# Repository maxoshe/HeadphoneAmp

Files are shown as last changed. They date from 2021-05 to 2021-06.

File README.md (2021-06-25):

# HeadphoneAmp

In this project I have designed and implemented a Low Noise Headphone Amplifier. The purpose of this project was to gain a better understanding of the design process of printed circuit boards and to practice common engineering tasks such as drafting a schematic, generating a pcb layout from a schematic, generating a bill of materials and soldering components to a PCB.

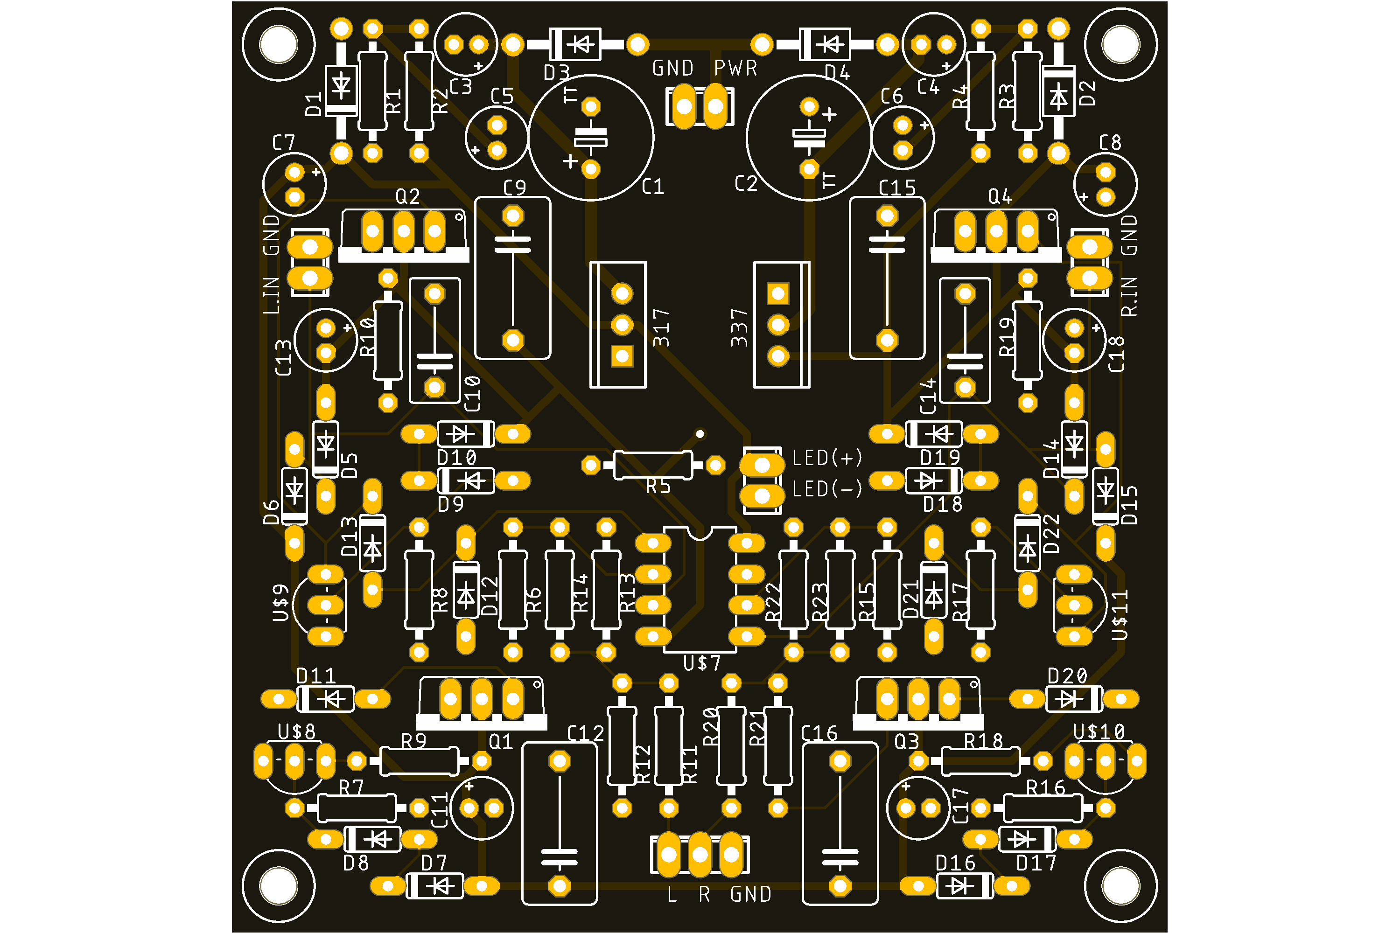
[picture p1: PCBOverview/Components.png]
pcb layout


## Design

The circuit is composed of three smaller circuits, a power supply and two mono
audio channels.
Dividing the entire schematic into three portions helped later with the board layout since I was able to easily separate the power supply from the signal path.

### Power Supply

The power supply receives 15V AC at the input terminal and outputs -15V DC and +15V DC at the output terminals. It achieves the rectification by using a combination of diodes, capacitors, resistors and voltage regulators.

### Audio Channels

Since this is a stereo amplifier, it is crucial to get the gain and signal to noise ratio of each individual mono channel to match. This is why the left and right audio channel schematics are exactly the same. There will still be some small differences since the tolerance of the components can’t be 0% but this difference is hardly noticeable.

The left and right audio channels both receive an audio signal and amplify it using a non inverting amplifier. The operational amplifier that is used in the circuit is a OP275, with two channels on the same IC chip.

## Layout

I’ve placed the power supply components in the upper corner of the board far from the signal path. By doing so I reduced the 60hz noise that can be caused by induction, since the wires carrying 15V AC are far from the wires that carry audio signal.
Another improvement to the layout was to set different trace thickness for power and signal traces.
The majority of the back panel was used as a ground plane. This helps to further reduce noise. For the connections from the PCB to external components I used terminal block plugs, it helped with keeping the design clean and flexible when it comes to connecting and disconnecting external components.

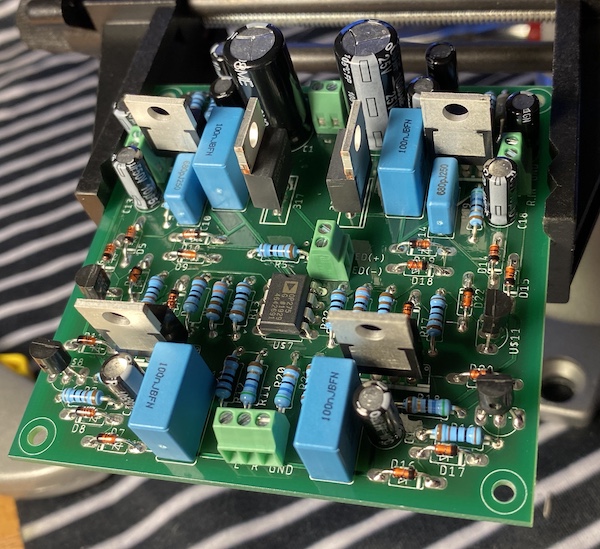
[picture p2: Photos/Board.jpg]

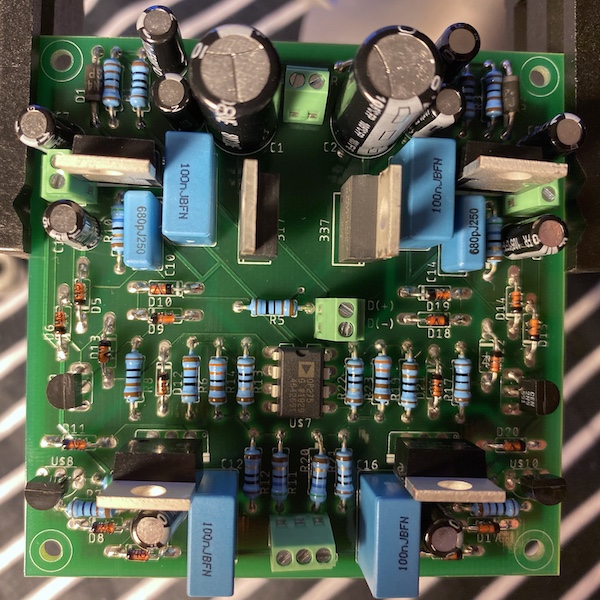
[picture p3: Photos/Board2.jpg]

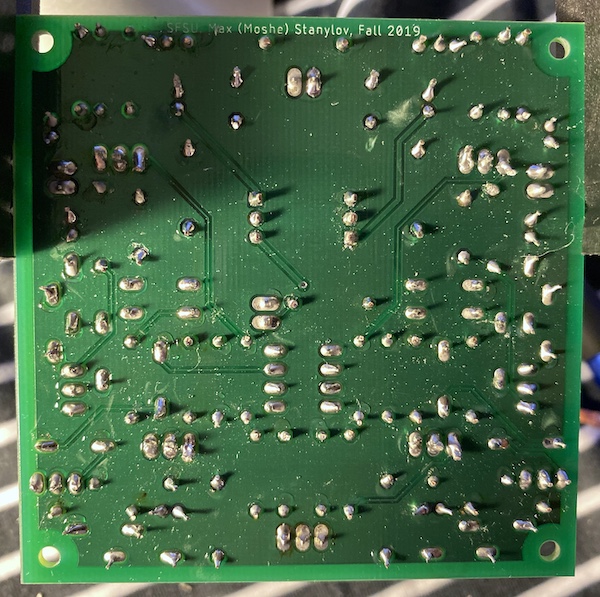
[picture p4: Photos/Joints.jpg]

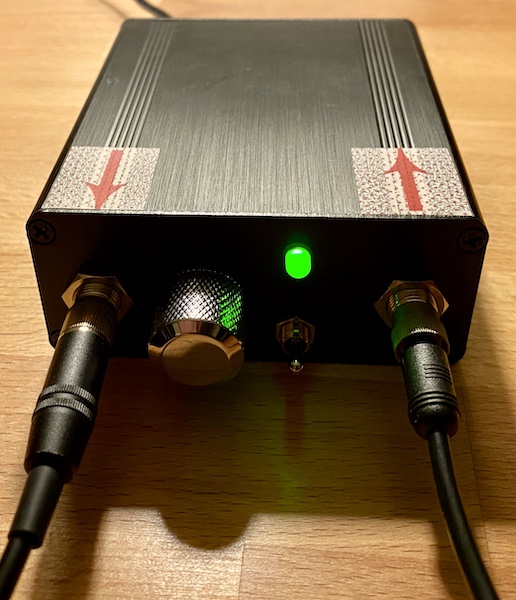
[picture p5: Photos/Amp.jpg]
enclosure


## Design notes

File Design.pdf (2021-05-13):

ENGR 301-01
Dec 17 2019
Moshe Stanylov

FINAL PROJECT: LOW NOISE HEADPHONE AMPLIFIER

Objective:
In this project I have designed and implemented a Low Noise Headphone Amplifier. The purpose of this project was to gain a better understanding of the design process of printed circuit boards and to practice common engineering tasks such as drafting a schematic, generating a pcb layout from a schematic, generating a bill of materials and soldering components to a PCB.

Design:

Schematic: The circuit is composed of three smaller circuits, a power supply and two mono audio channels.

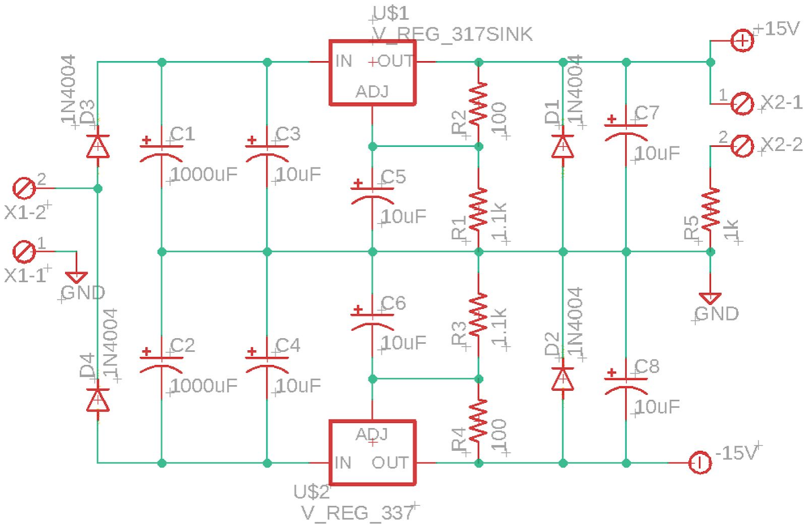
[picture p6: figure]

Fig.1 Power supply

The power supply in Fig.1 receives 15V AC at the input terminal labeled X1−2

from a
120V − 15V AC/AC transformer and outputs a − 15V DC and a + 15V DC at the output terminals labeled − 15V and + 15V . It achieves the rectification by using a combination of diodes, capacitors, resistors and voltage regulators.

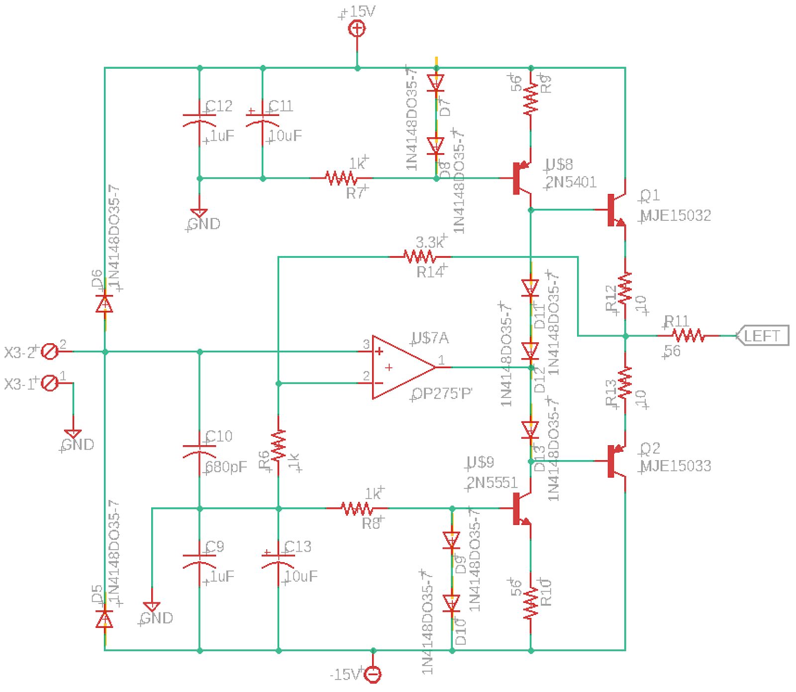
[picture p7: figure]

Fig.2 Left audio channel

Since this is a stereo amplifier, it is crucial to get the gain and signal to noise ratio of each individual mono channel to match. This is why the left and right audio channel schematics are exactly the same. There will still be some small differences since the tolerance of the components can’t be 0% but this difference is hardly noticeable.

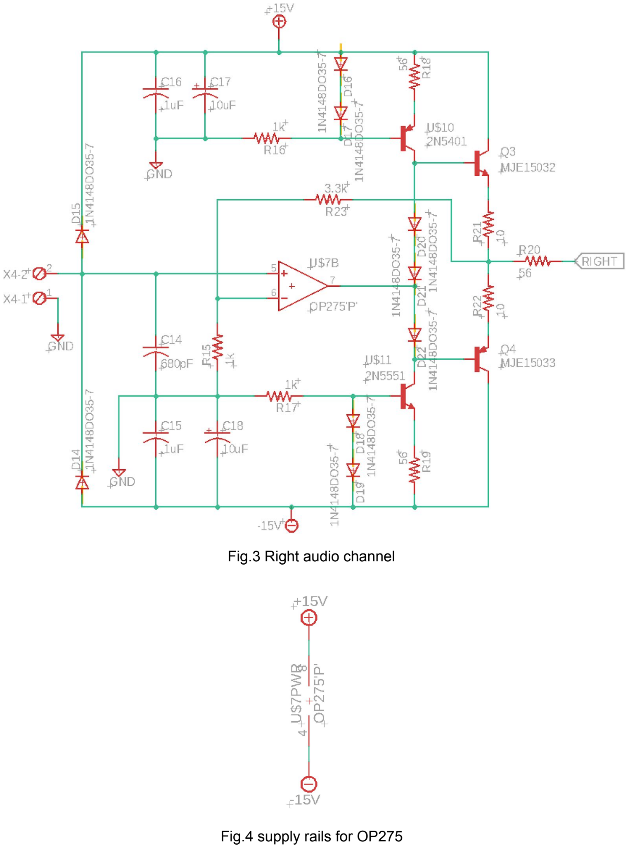
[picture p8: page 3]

Fig.3 Right audio channel

Fig.4 supply rails for OP275

The left and right audio channels both receive an audio signal and amplify it using a non inverting amplifier. The operational amplifier that is used in the circuit is a OP275, with two channels sharing the same IC.
Dividing the entire schematic into three portions helped later with the board layout since I was able to easily separate the power supply from the signal path.

Board: While working on the board layout I made sure that the packages that I use in the layout match with the components that I will be ordering. I also tried to keep things consistent and use components of different values from the same series.

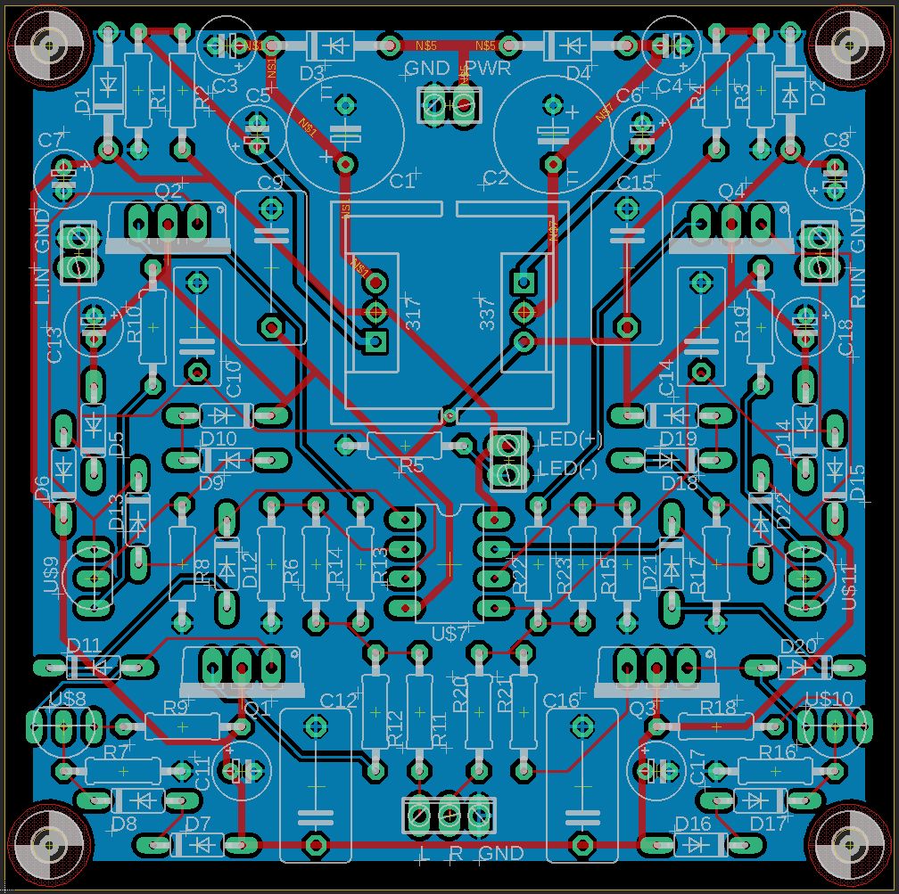
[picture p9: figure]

Fig.5 Board layout in Eagle

I’ve placed the power supply components in the upper corner of the board far from the signal path. By doing so I reduced the 60hz noise that can be caused by induction, since the wires carrying 15V AC are far from the wires that carry audio signal.
Another improvement to the layout was to define net class parameters, I’ve defined the wires carrying 15V AC to be the thickest, the wires carrying ± 15V DC thick and the rest was set to default.
The majority of the back panel was used as a ground plane. This helps to further reduce noise. For the connections from the PCB to external components I used terminal block plugs, it helped with keeping the design clean and flexible when it comes to connecting and disconnecting external components.
The final stage of the PCB layout was to create labels for the terminals and to make sure all of the component labels are placed in a way that is easy to read.

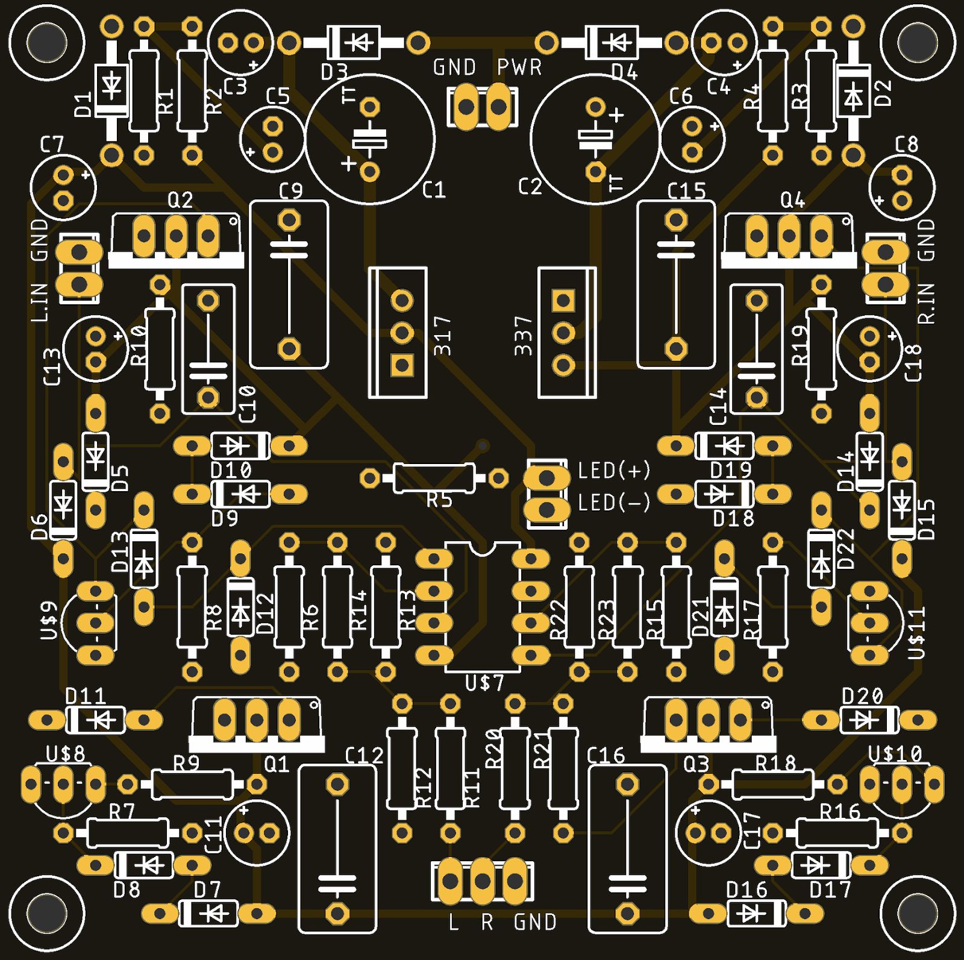
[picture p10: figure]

Fig.6 Board preview in Eagle

Components List:
Description | Part number | Quantity
Metal Film Resistors - 100Ω ± 1% | MBB02070C1000FCT00 | 2
Metal Film Resistors - 1.1kΩ ± 1% | MBB02070C1101FRP00 | 2
Metal Film Resistors - 1kΩ ± 1% | MBB02070C1001FC100 | 7
Metal Film Resistors - 56Ω ± 1% | MBB02070C5609FC100 | 6
Metal Film Resistors - 10Ω ± 1% | MBB02070C1009FCT00 | 4
Metal Film Resistors - 3.3kΩ ± 1% | MBB02070C3301FC100 | 2
Aluminum Electrolytic Capacitors - 1000μF ± 20% | EEU-FP1E102 | 2
Aluminum Electrolytic Capacitors - 10μF ± 20% | EEU-FR1H100 | 10
Film Capacitors - 0.68μF ± 5% | PHE450HK3680JR17 | 2
Film Capacitors - 0.1μF ± 5% | PHE450HA6100JR17 | 4
Diodes - Rectifiers | 1N4004GP-E3/73 | 4
Diodes - General Purpose | 1N4148TR | 18
Bipolar Transistors - PNP | 2N5401 | 2
Bipolar Transistors - NPN | 2N5551 | 2
Bipolar Transistors - NPN | MJE15032G | 2
Bipolar Transistors - PNP | MJE15033G | 2
Linear Voltage Regulators | LM317T/NOPB | 1
Linear Voltage Regulators | LM337T/NOPB | 1
Potentiometers - 10kΩ | PDB182-E420K-103A | 1
Op Amp - Dual Bipolar/JFET | OP275GPZ | 1
Fixed Terminal Blocks - 2 Positions | 1725656 | 4
Fixed Terminal Blocks - 3 Positions | 1725669 | 1
1/4" TRS | NYS230 | 2

Fuse - 1A | 0ADAP1000-RE | 1
Toggle Switch - SPDT ON-ON | 100SP1T1B1M1QEH | 1
Power Supply Jack - 5.5 × 2.1mm | B07MPS3QD8 | 1
Aluminum Enclosure - 88 × 38 × 100mm | LKHZ002 | 1
Table 1 Component List

Board Testing:

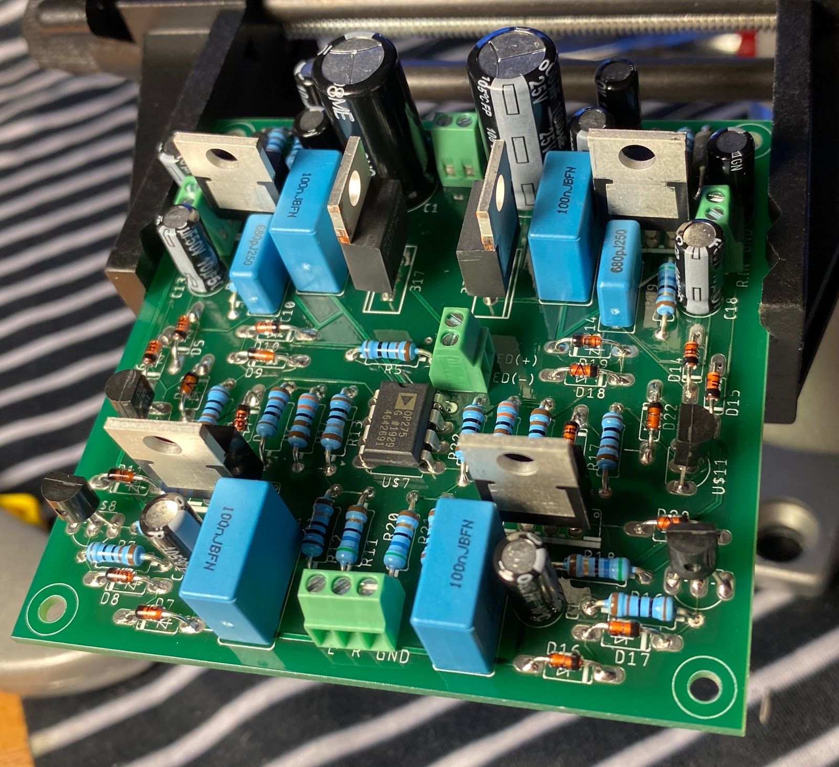
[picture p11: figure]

Fig.7 Board

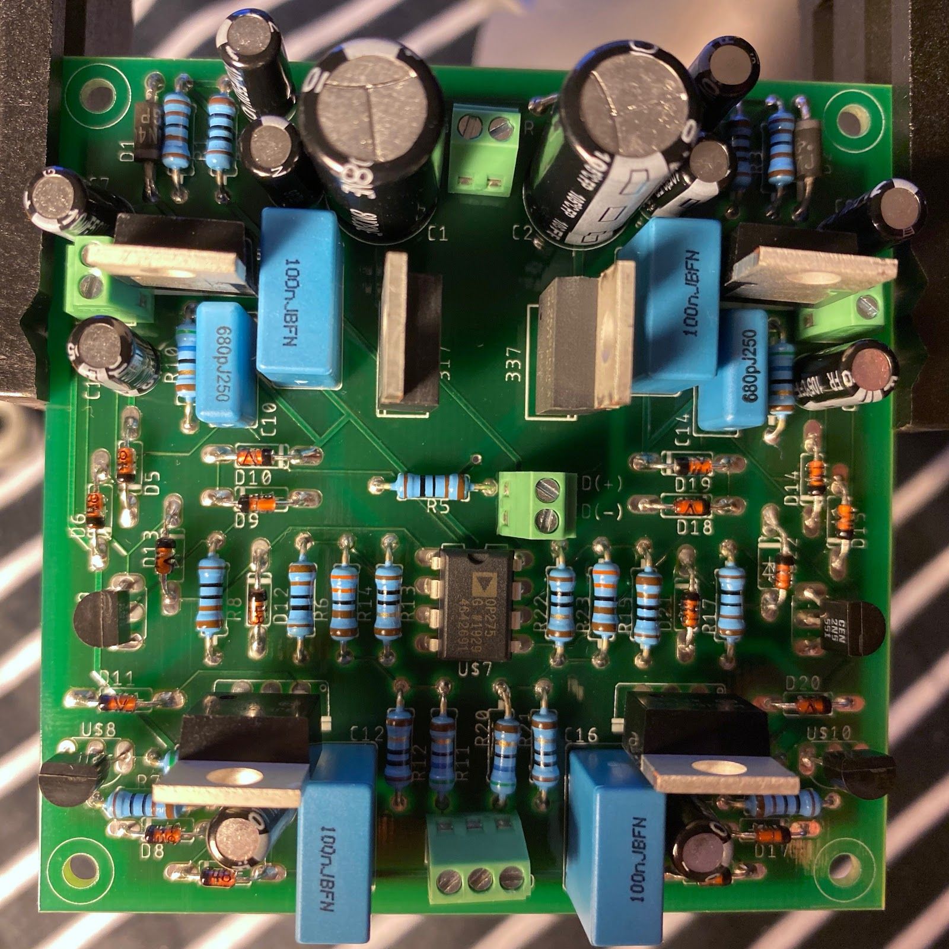
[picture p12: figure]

Fig.8 Board top

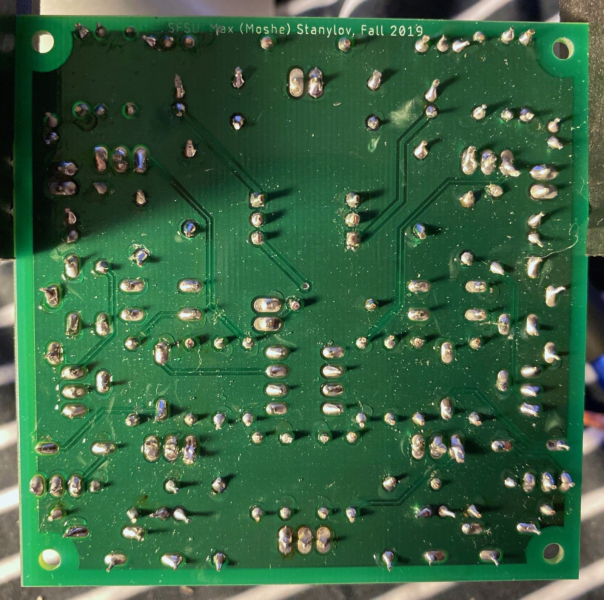
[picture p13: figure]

Fig.9 Board bottom

I’ve tested the board using a number of different inputs. The first test was done with an Audio Technica turntable, I’ve used an RCA to 3.5mm adapter in order to connect the output of the turntable to the input stage of the headphone amplifier and tested the potentiometer to see that I can control the volume and that the left and right channels are consistent. Everything worked but the potentiometer was wired backwards with the clockwise rotation decreasing the volume. Interchanging the connections on lugs 1 and 3 fixed the problem.
I then repeated the test twice using a laptop and a bass guitar as inputs, the circuit worked with both. The bass guitar was coming only from one channel since the output jack on a guitar is mono, this can be fixed by using an adapter.

Conclusion:
This project helped my understanding of the design and implementation process of printed circuit boards. It provided me with a lot of useful experience with Eagle. I learned how to create a board layout that takes into consideration the requirements of the design. Using terminal blocks for external components and paying attention to details such as package sizes of components, lead spacing and component placement made the assembling stage quick and easy.

Additional information:

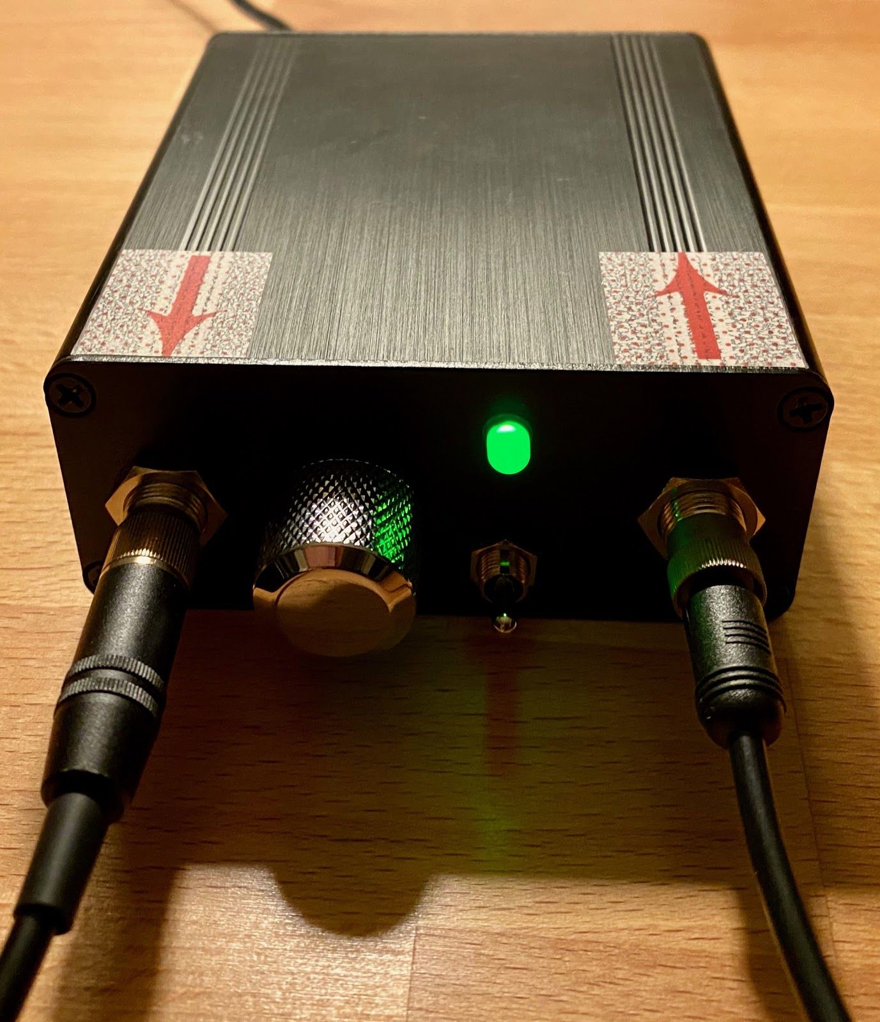
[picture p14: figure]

Fig.10 Enclosure

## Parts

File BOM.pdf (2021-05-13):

Component | Type | Part | Qty
Metal Film Resistor | 100Ω | MBB02070C1000FCT00 | 2
Metal Film Resistor | 1.1kΩ | MBB02070C1101FRP00 | 2
Metal Film Resistor | 1kΩ | MBB02070C1001FC100 | 7
Metal Film Resistor | 56Ω | MBB02070C5609FC100 | 6
Metal Film Resistor | 10Ω | MBB02070C1009FCT00 | 4
Metal Film Resistor | 3.3kΩ | MBB02070C3301FC100 | 2
Aluminum Electrolytic Capacitor | 1000μF | EEU-FP1E102 | 2
Aluminum Electrolytic Capacitor | 10μF | EEU-FR1H100 | 10
Film Capacitor | 0.68μF | PHE450HK3680JR17 | 2
Film Capacitor | 0.1μF | PHE450HA6100JR17 | 4
Diode | Rectifier | 1N4004GP-E3/73 | 4
Diode | General Purpos | 1N4148TR | 18
Bipolar Transistor | PNP | 2N5401 | 2
Bipolar Transistor | NPN | 2N5551 | 2
Bipolar Transistor | NPN | MJE15032G | 2
Bipolar Transistor | PNP | MJE15033G | 2
Linear Voltage Regulator | | LM317T/NOPB | 1
Linear Voltage Regulator | | LM337T/NOPB | 1
Potentiometer | 10kΩ | PDB182-E420K-103A | 1
Op Amp - Dual Bipolar | JFET | OP275GPZ | 1
Fixed Terminal Block | 2 Positions | 1725656 | 4
Fixed Terminal Block | 3 Positions | 1725669 | 1
1/4" TRS connector | | NYS230 | 2
Fuse | 1A | 0ADAP1000-RE | 1
Toggle Switch - SPDT ON-ON | | 100SP1T1B1M1QEH | 1
Power Supply Jack | | B07MPS3QD8 | 1
Aluminum Enclosure | 88 × 38 × 100mm | LKHZ002 | 1

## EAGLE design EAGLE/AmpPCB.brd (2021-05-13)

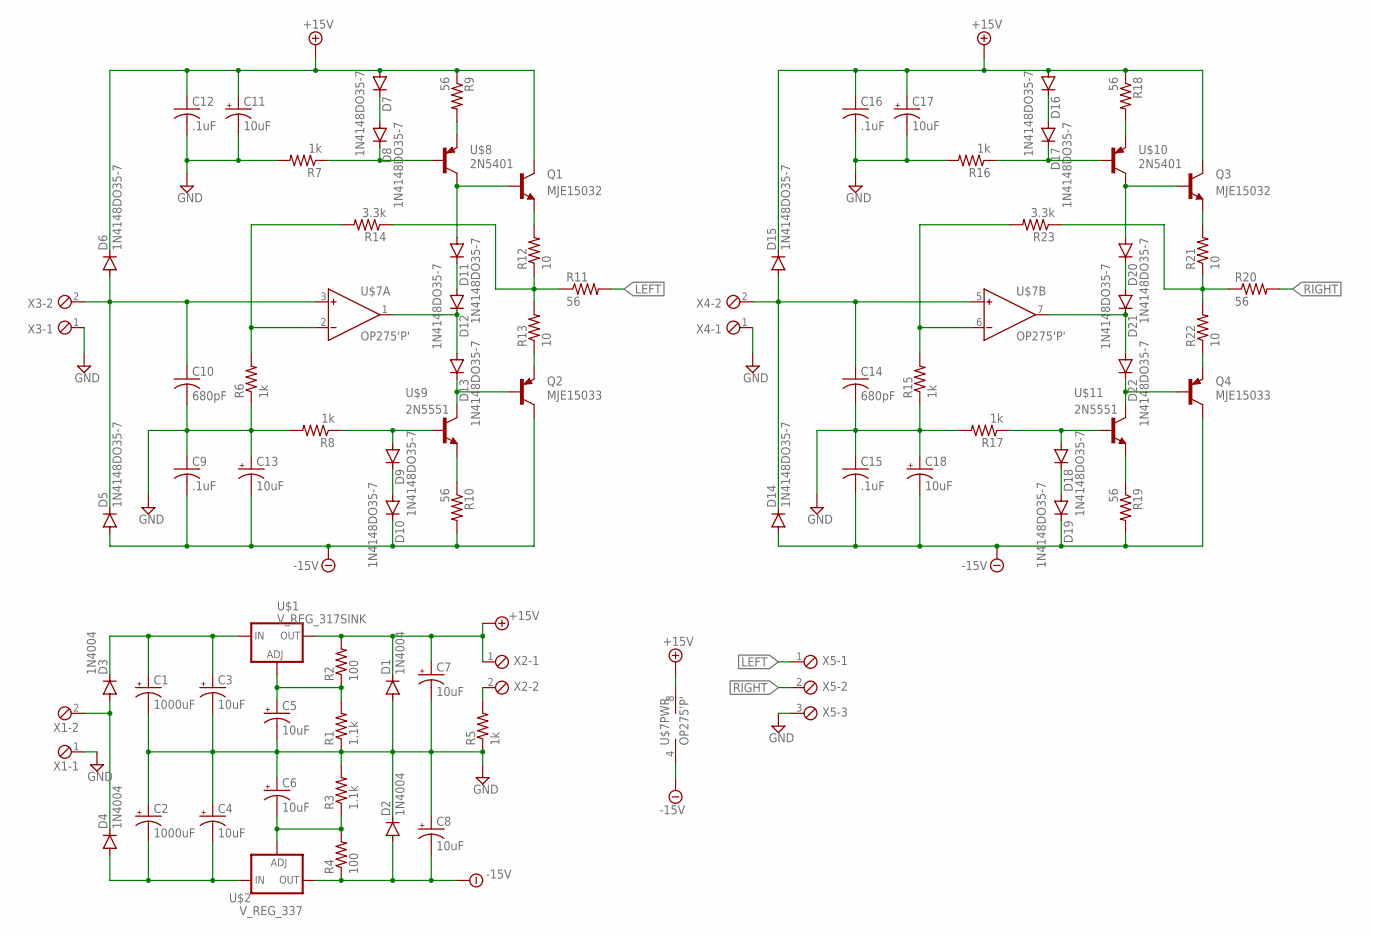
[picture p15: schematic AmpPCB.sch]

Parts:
C1, C2: 1000uF; TT5D10
C3, C4, C5, C6, C7, C8, C11, C13, C17, C18: 10uF; E2-5
C9, C12, C15, C16: .1uF; C102-064X133
C10, C14: 680pF; C075-042X103
D1, D2, D3, D4: 1N4004; DO41-10
D5, D6, D7, D8, D9, D10, D11, D12, D13, D14, D15, D16, D17, D18, D19, D20, D21, D22: 1N4148DO35-7; DO35-7
Q1, Q3: MJE15032; TO220V
Q2, Q4: MJE15033; TO220V
R1, R3: 1.1k; 0207/10
R2, R4: 100; 0207/10
R5, R6, R7, R8, R15, R16, R17: 1k; 0207/10
R9, R10, R11, R18, R19, R20: 56; 0207/10
R12, R13, R21, R22: 10; 0207/10
R14, R23: 3.3k; 0207/10
U$1: V_REG_317SINK; TO220-ADJ
U$2: V_REG_337; TO220-ADJ-NEG
U$7: OP275'P'; DIL08
U$8, U$10: 2N5401
U$9, U$11: 2N5551
X1, X2, X3, X4: MPT2; 2POL254
X5: MPT3; 3POL254

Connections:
+15V: C7.+, C11.+, C12.1, C16.1, C17.+, D1.C, D6.C, D7.A, D15.C, D16.A, Q1.2 (C), Q3.2 (C), R2.2, R9.1, R18.1, U$1.OUT, U$7.8 (V+), X2.1
-15V: C8.-, C9.2, C13.-, C15.2, C18.-, D2.A, D5.A, D10.C, D14.A, D19.C, Q2.2 (C), Q4.2 (C), R4.1, R10.2, R19.2, U$2.OUT, U$7.4 (V-)
GND: C1.-, C2.+, C3.-, C4.+, C5.-, C6.+, C7.-, C8.+, C9.1, C10.2, C11.-, C12.2, C13.+, C14.2, C15.1, C16.2, C17.-, C18.+, D1.A, D2.C, R1.1, R3.2, R5.1, R6.1, R7.2, R8.2, R15.1, R16.2, R17.2, X1.1, X3.1, X4.1, X5.3
LEFT: R11.2, X5.1
unnamed: C1.+, C3.+, D3.C, U$1.IN
unnamed: C10.1, D5.C, D6.A, U$7.3 (IN+), X3.2
unnamed: C5.+, R1.2, R2.1, U$1.ADJ
unnamed: R10.1, U$9.E
unnamed: D3.A, D4.C, X1.2
unnamed: C6.-, R3.1, R4.2, U$2.ADJ
unnamed: C2.-, C4.-, D4.A, U$2.IN
unnamed: D9.A, R8.1, U$9.B
unnamed: R5.2, X2.2
unnamed: D9.C, D10.A
unnamed: R6.2, R14.2, U$7.2 (IN-)
unnamed: D13.C, Q2.1 (B), U$9.C
unnamed: D12.C, D13.A, U$7.1 (OUT)
unnamed: D11.C, D12.A
unnamed: Q1.3 (E), R12.2
unnamed: Q2.3 (E), R13.1
unnamed: R11.1, R12.1, R13.2, R14.1
unnamed: D11.A, Q1.1 (B), U$8.C
unnamed: D8.C, R7.1, U$8.B
unnamed: D7.C, D8.A
unnamed: R9.2, U$8.E
unnamed: D18.A, R17.1, U$11.B
unnamed: D18.C, D19.A
unnamed: R15.2, R23.2, U$7.6 (IN-)
unnamed: C14.1, D14.C, D15.A, U$7.5 (IN+), X4.2
unnamed: R19.1, U$11.E
unnamed: D22.C, Q4.1 (B), U$11.C
unnamed: D21.C, D22.A, U$7.7 (OUT)
unnamed: D20.C, D21.A
unnamed: Q4.3 (E), R22.1
unnamed: R20.1, R21.1, R22.2, R23.1
unnamed: Q3.3 (E), R21.2
unnamed: D20.A, Q3.1 (B), U$10.C
unnamed: D17.C, R16.1, U$10.B
unnamed: D16.C, D17.A
unnamed: R18.2, U$10.E
RIGHT: R20.2, X5.2

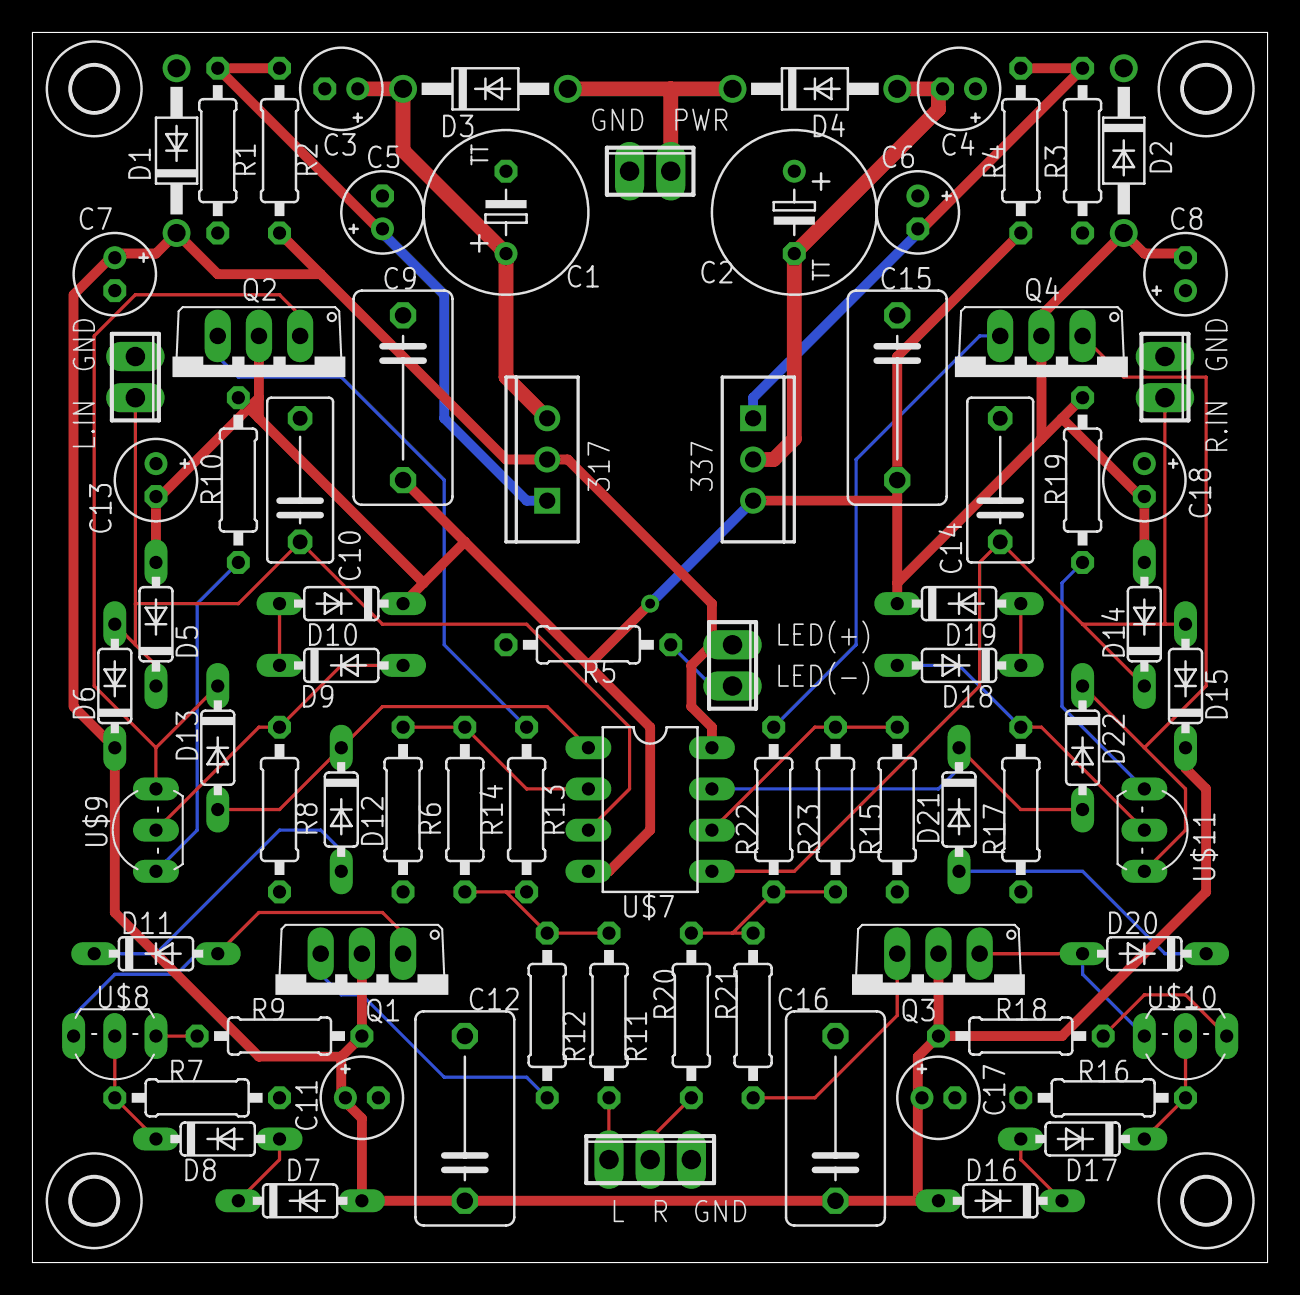
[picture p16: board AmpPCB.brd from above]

Board: 2 copper layers, 76.2 x 75.9 mm, 83 parts (0 on the bottom side), 41 nets.

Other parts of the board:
U$3, U$4, U$5, U$6: 2,8

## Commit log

2021-05-13 Added EAGLE files
    [AmpPCB.brd, AmpPCB.sch]
2021-05-13 Added PCB layouts
2021-05-13 Added BOM
    [BOM.xlsx]
